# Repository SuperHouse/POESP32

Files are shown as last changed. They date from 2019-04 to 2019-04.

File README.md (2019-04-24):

ESP32 Controller with Ethernet and PoE
======================================
Copyright 2018 SuperHouse Automation Pty Ltd  www.superhouse.tv  

ESP32 controller board with Ethernet and PoE support.

Includes 2 x I/O Breakout headers (12-pin IDC) compatible with other
I/O Breakout boards from SuperHouse.

More information is available at:

  http://www.superhouse.tv/poesp32

INSTALLATION
------------
The design is saved as an EAGLE project. EAGLE PCB design software is
available from www.cadsoftusa.com free for non-commercial use. To use
this project download it and place the directory containing these files
into the "eagle" directory on your computer. Then open EAGLE and
navigate to the project.

DISTRIBUTION
------------
The specific terms of distribution of this project are governed by the
license referenced below.

LICENSE
-------
Licensed under the TAPR Open Hardware License (www.tapr.org/OHL).
The "license" folder within this repository also contains a copy of
this license in plain text format.

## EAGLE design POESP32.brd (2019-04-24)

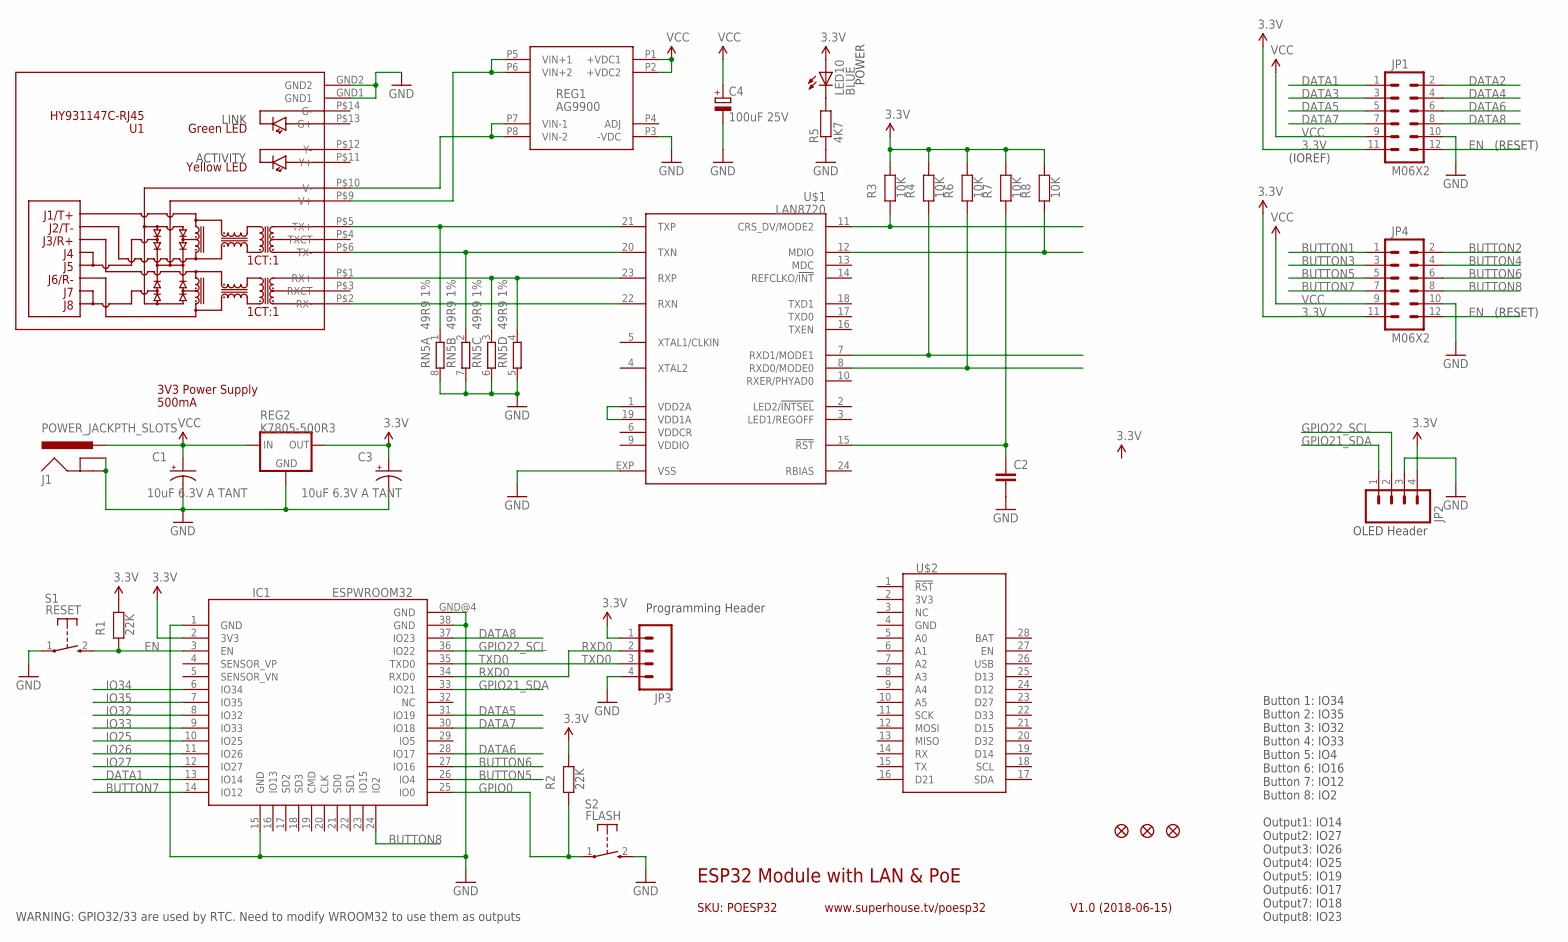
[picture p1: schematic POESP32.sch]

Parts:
C1, C3: 10uF 6.3V A TANT; EIA3216
C2: CAP0805; 0805
C4: 100uF 25V; PANASONIC_D
FID1, FID2, FID3: FIDUCIAL1X2.5; FIDUCIAL-1X2.5
IC1: ESPWROOM32
J1: POWER_JACKPTH_SLOTS; POWER_JACK_PTH_SLOTS
JP1, JP4: M06X2; 2X6-SHROUDED
JP2, JP3: M04PTH; 1X04
LED10: BLUE; LED-0603
R1, R2: 22K; 0603@2
R3, R4, R6, R7, R8: 10K; 0603@2
R5: 4K7; 0603
REG1: AG9900
REG2: K7805-500R3; K78XX-500R3
RN5: 49R9 1%; CAY16
S1: RESET; TACTILE_SWITCH_SMD_2PIN_TINY
S2: FLASH; TACTILE_SWITCH_SMD_2PIN_TINY
U1: HY931147C-RJ45; HY931147C
U$1: LAN8720; QFN24
U$2: FEATHER

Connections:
3.3V: C3.A (+), IC1.2 (3V3), JP1.11, JP2.4, JP3.1, JP4.11, LED10.A, R1.1, R2.1, R3.1, R4.1, R6.1, R7.1, R8.1, REG2.3 (OUT)
BUTTON1: JP4.1
BUTTON2: JP4.2
BUTTON3: JP4.3
BUTTON4: JP4.4
BUTTON5: IC1.26 (IO4), JP4.5
BUTTON6: IC1.27 (IO16), JP4.6
BUTTON7: IC1.14 (IO12), JP4.7
BUTTON8: IC1.24 (IO2), JP4.8
DATA1: IC1.13 (IO14), JP1.1
DATA2: JP1.2
DATA3: JP1.3
DATA4: JP1.4
DATA5: IC1.31 (IO19), JP1.5
DATA6: IC1.28 (IO17), JP1.6
DATA7: IC1.30 (IO18), JP1.7
DATA8: IC1.37 (IO23), JP1.8
EN: IC1.3 (EN), JP1.12, JP4.12, R1.2, S1.2 (S)
GND: C1.C (-), C2.2, C3.C (-), C4.-, IC1.1 (GND), IC1.15 (GND), IC1.38 (GND), IC1.GND@4 (GND), J1.GND, J1.GNDBREAK, JP1.10, JP2.3, JP3.4, JP4.10, R5.1, REG1.P3 (-VDC), REG2.2 (GND), RN5.5 (2), RN5.6 (2), RN5.7 (2), RN5.8 (2), S1.1, S2.2 (S), U1.GND1, U1.GND2, U$1.EXP (VSS)
GPIO0: IC1.25 (IO0), R2.2, S2.1
GPIO21_SDA: IC1.33 (IO21), JP2.1
GPIO22_SCL: IC1.36 (IO22), JP2.2
IO25: IC1.10 (IO25)
IO26: IC1.11 (IO26)
IO27: IC1.12 (IO27)
IO32: IC1.8 (IO32)
IO33: IC1.9 (IO33)
IO34: IC1.6 (IO34)
IO35: IC1.7 (IO35)
unnamed: RN5.1, U1.P$5 (TX+), U$1.21 (TXP)
unnamed: REG1.P5 (VIN+1), REG1.P6 (VIN+2), U1.P$9 (V+)
unnamed: REG1.P7 (VIN-1), REG1.P8 (VIN-2), U1.P$10 (V-)
unnamed: RN5.2 (1), U1.P$6 (TX-), U$1.20 (TXN)
unnamed: RN5.3 (1), RN5.4 (1), U1.P$1 (RX+), U$1.23 (RXP)
unnamed: U1.P$2 (RX-), U$1.22 (RXN)
unnamed: U$1.1 (VDD2A), U$1.19 (VDD1A)
unnamed: R4.2, U$1.7 (RXD1/MODE1)
unnamed: R6.2, U$1.8 (RXD0/MODE0)
unnamed: R3.2, U$1.11 (CRS_DV/MODE2)
unnamed: C2.1, R7.2, U$1.15 (!RST)
unnamed: R8.2, U$1.12 (MDIO)
unnamed: LED10.C, R5.2
RXD0: IC1.34 (RXD0), JP3.2
TXD0: IC1.35 (TXD0), JP3.3
VCC: C1.A (+), C4.+, J1.PWR, JP1.9, JP4.9, REG1.P1 (+VDC1), REG1.P2 (+VDC2), REG2.1 (IN)
VDDCR: U$1.6 (VDDCR)
VDDIO: U$1.9 (VDDIO)

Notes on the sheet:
SKU: POESP32
ESP32 Module with LAN & PoE
V1.0 (2018-06-15)
www.superhouse.tv/poesp32
Button 1: IO34 Button 2: IO35 Button 3: IO32 Button 4: IO33 Button 5: IO4 Button 6: IO16 Button 7: IO12 Button 8: IO2 Output1: IO14 Output2: IO27 Output3: IO26 Output4: IO25 Output5: IO19 Output6: IO17 Output7: IO18 Output8: IO23
POWER
3V3 Power Supply
500mA
(IOREF)
WARNING: GPIO32/33 are used by RTC. Need to modify WROOM32 to use them as outputs
OLED Header
Programming Header
(RESET)
LINK
ACTIVITY

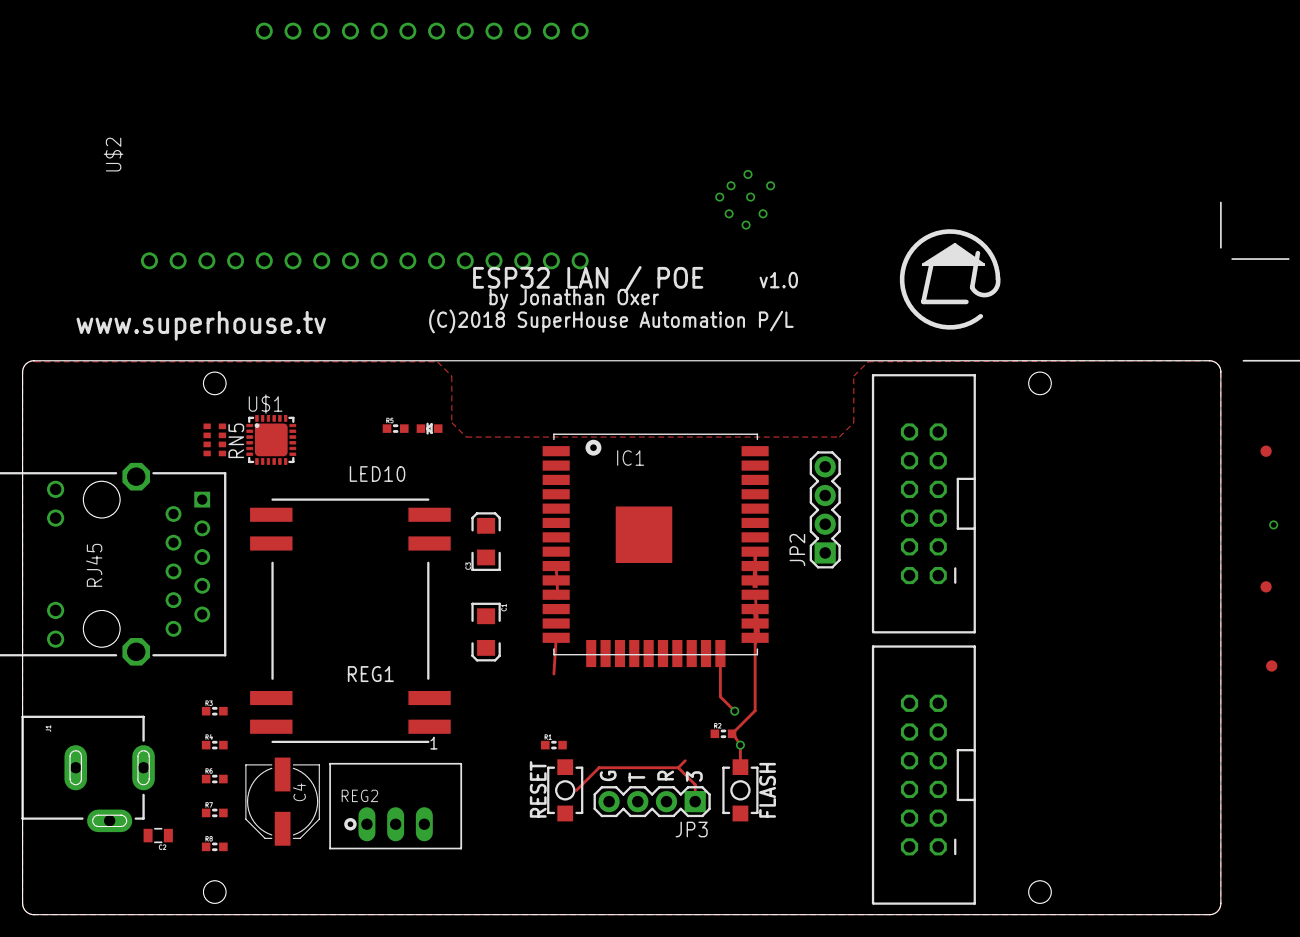
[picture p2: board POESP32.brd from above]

Board: 2 copper layers, 106.0 x 49.0 mm, 30 parts (0 on the bottom side), 31 nets.

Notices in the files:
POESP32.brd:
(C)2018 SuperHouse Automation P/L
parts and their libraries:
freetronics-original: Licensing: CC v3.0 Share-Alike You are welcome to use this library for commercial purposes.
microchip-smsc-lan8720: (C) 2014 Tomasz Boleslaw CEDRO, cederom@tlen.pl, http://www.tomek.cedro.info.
